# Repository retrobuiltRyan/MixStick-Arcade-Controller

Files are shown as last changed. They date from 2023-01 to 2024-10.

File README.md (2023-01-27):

# MixStick-Arcade-Controller
Compact, universal 12-button WASD layout USB arcade controller compatible with Mac, PC, MiSTer, and more. The MixStick is a hybrid of a mechanical keyboard and budget arcade fight stick, but forced into the constraints of economical parts and versatility. Unlike all the dedicated things it’s inspired by, it doesn’t do anything particularly well, but at the cost of parts I can confidently say it punches above its weight compared to the $250+ mixbox-like alternatives. Can also be a macro keyboard when paird with AntiMicroX. Enclosure design files are available to remix/ suite whatever application you need. Gerber files are available to make your own. PCB design files will come a bit later.
P1060787
P1060708
Detailed about.
The circuit board is discrete input (not a row column matrix) arduino pro micro arcade controller. Or just a generic USB HID game controller with a modular enclosure. The circuit is designed as pin to pin compatible with the open source and awesome daemon byte arcade encoder firmware by MickGyver. I’ve added RGB leds for clout. Set your IDE to an Arduino Leonardo or Pro Micro, and upload MickGyver Firmware. Plug this into a Mac or PC and that’s it. You’ve got a nice compact gaming controller with more buttons than you need.  
The backside of PCB has jumpers to move (or duplicate) two buttons from the top function to adjacent of WASD cluster.
P1060691

CAD files have two main variatations, the Straight Layout or the Angled Offset layout. This orientiation influnces the location of the cordpass through. Pick the correct 3D model or change the dimension in the solidworks model. 
MixStick 3D print Base
MixStick 3D print Base overview
MixStick 3D control panel Dimensions

P1060748
P1060796
P1060783
P1060782

PCB view

Parts you need:
Addressable RGB LEDs SK6812 MINI-E RGB (https://www.aliexpress.us/item/2255800289371100.html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)
1206 220-330ohm resistor RMCF1206JT330RCT-ND (https://www.digikey.com/short/mnfjbmt8) for the Addressable LED data line.
Cherry Mx 5pin CH197-ND (https://www.digikey.com/short/03p19mw3) or compatible key switch. RGB compatible (have a clearish body) are recommended. 

Extra Notes:
Use the enclosure files with your own ideas. This arcade controller was  made from a salvaged 3rd-party universal DDR circuit board. 
P1060760
P1060758

If using the WASDjoy modular PCBs see repository for laser cutable templates here: https://github.com/retrobuiltRyan/WASDjoy
P1060714

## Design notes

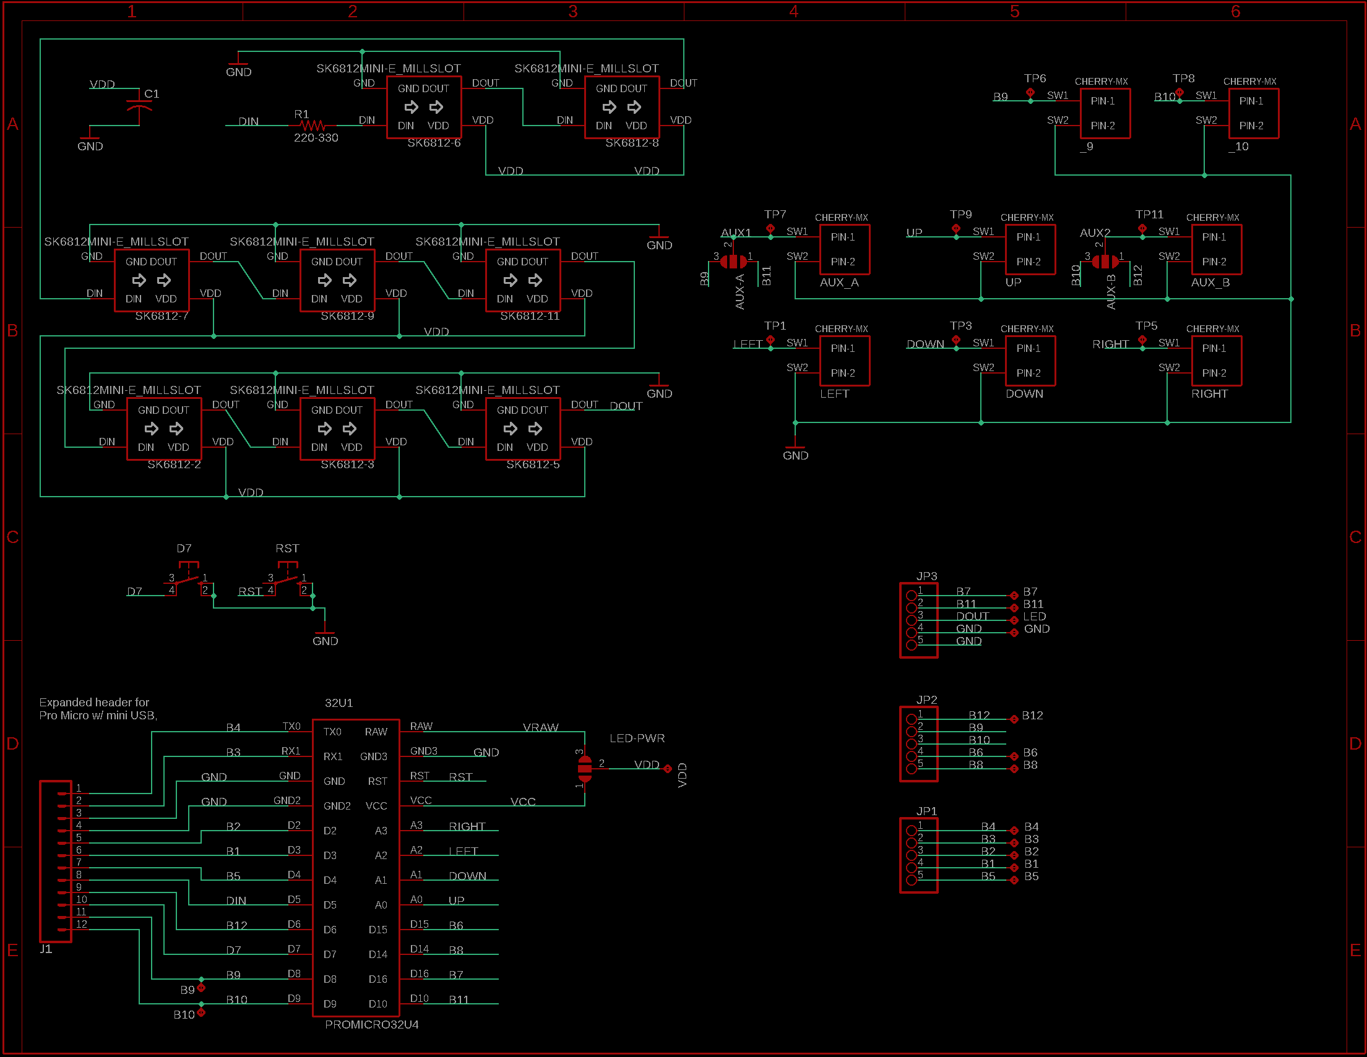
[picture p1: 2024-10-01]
Left Schematic.png

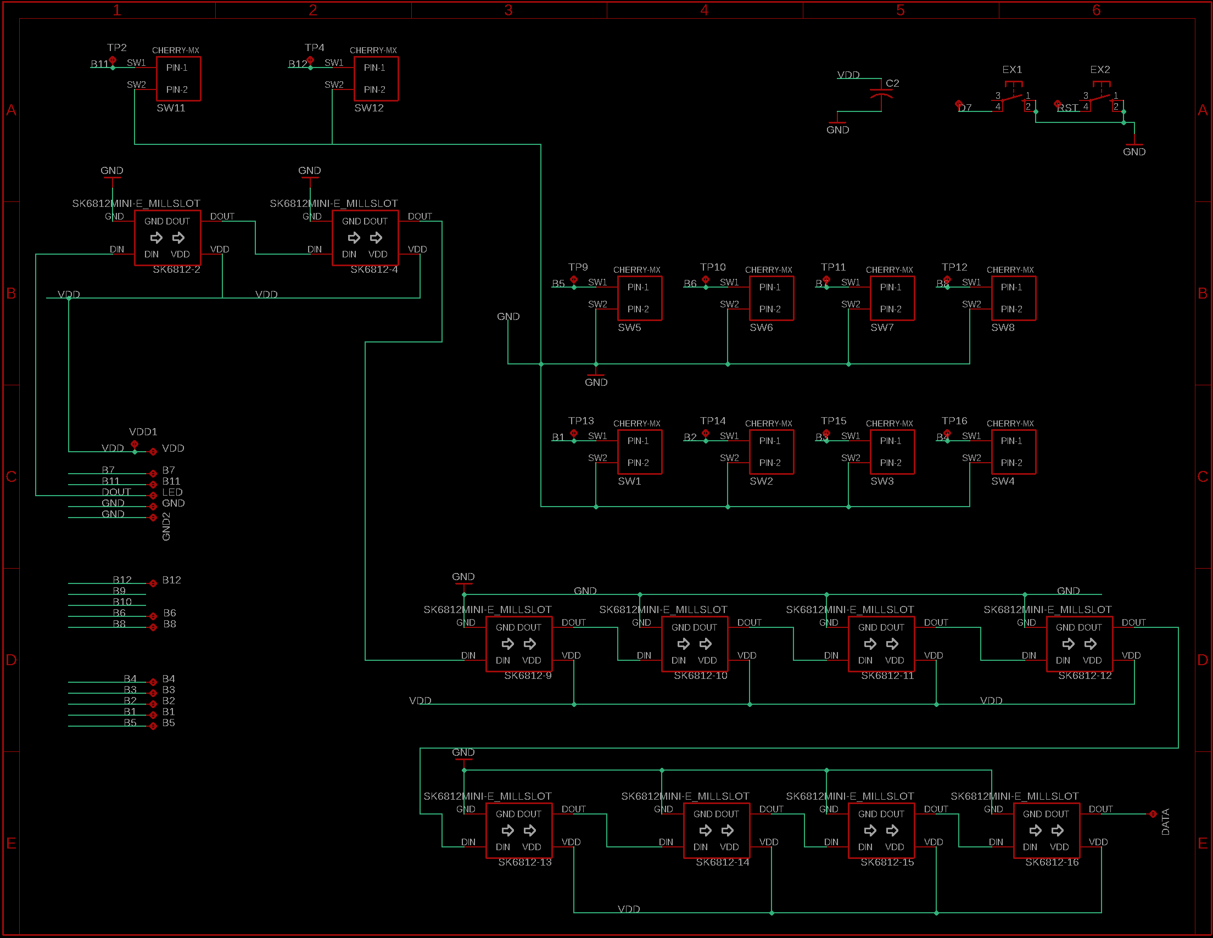
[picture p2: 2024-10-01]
Right Schematic.png

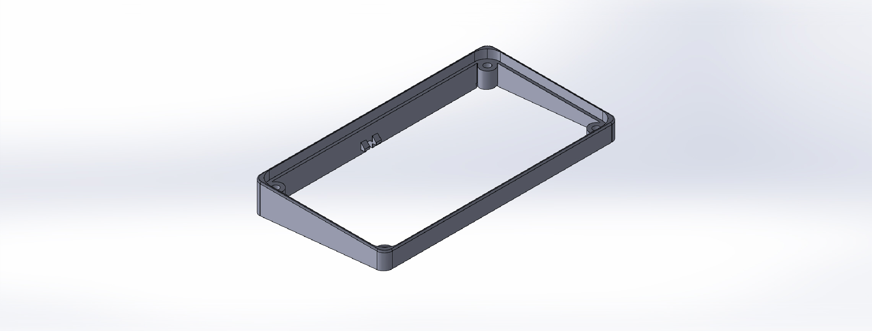
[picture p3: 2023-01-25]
MIXSTtick base v2.2 cord cutout for 15deg layout.JPG

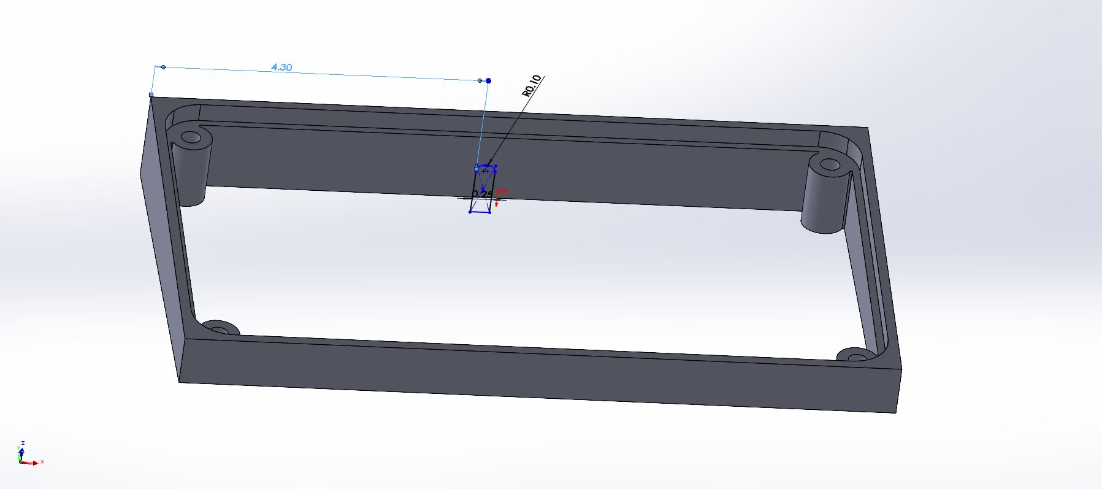
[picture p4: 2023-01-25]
MIXSTtick base v2.2 Cord Cutout explaination.JPG

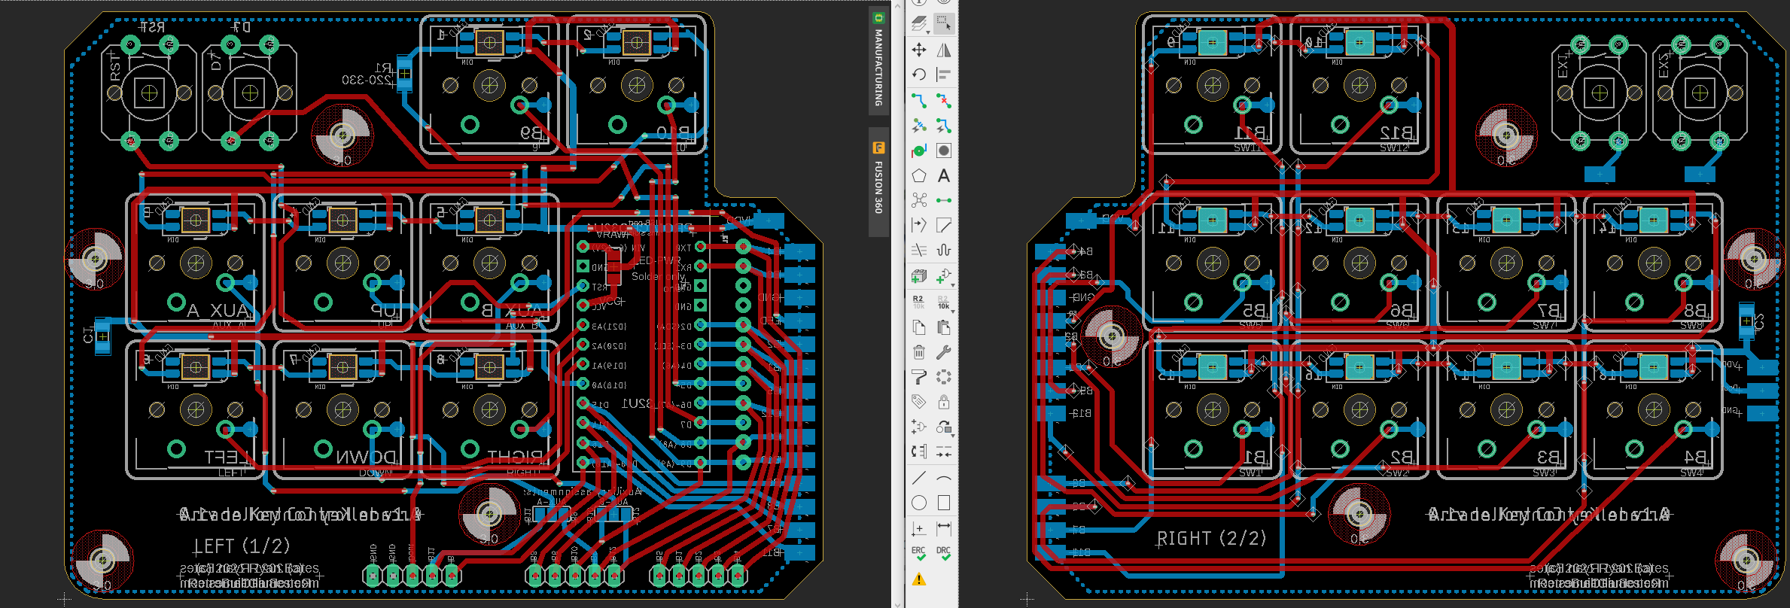
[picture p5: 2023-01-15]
PCB view.PNG

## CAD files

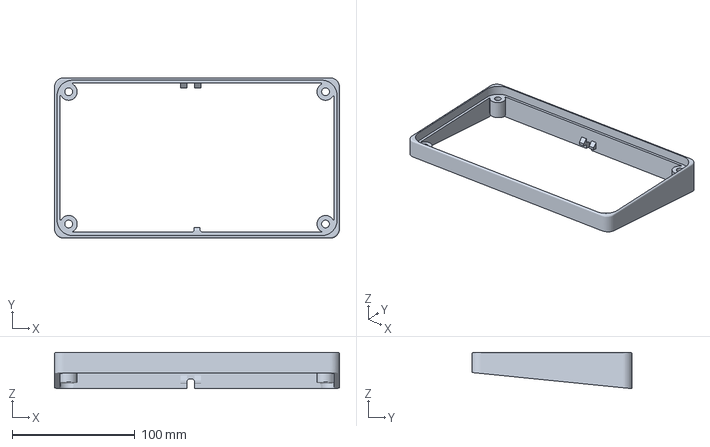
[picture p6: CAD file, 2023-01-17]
MIXSTtick base v2.2 cord cutout for 15deg layout.3MF
232.4 x 130.8 x 29.7 mm

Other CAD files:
MIXSTtick base v2.2 cord cut straight layout.SLDPRT
MIXSTtick base v2.2 cord cutout for straight layout.3MF
MIXSTtick base v2.2 cord cut 15deg offset layout.SLDPRT
MIXSTtick base v2.2 cord cutout for 15deg layout.STL
MIXSTtick base v2.2 cord cutout for straight layout.STL

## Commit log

2023-01-15 3D model (SolidWorks 2020) and Vector (Inkscape)
    [MIXSTtick base v2.2 the good version.SLDPRT]
2023-01-15 Gerbers (JLCPCB)
2023-01-25 3D + CAD Files
    SolidWorks, .stl, and .3mf
    [MIXSTtick base v2.2 cord cut 15deg offset layout.SLDPRT, MIXSTtick base v2.2 cord cut straight layout.SLDPRT, MIXSTtick base v2.2 cord cutout for 15deg layout.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]
2024-09-30 USB HIB Gamepad code with neopixel extras
    https://github.com/MickGyver/DaemonBite-Arcade-Encoder plus the basic example from Adafruit Neopixel library
2024-10-01 Schematic (Left and Right sides)
